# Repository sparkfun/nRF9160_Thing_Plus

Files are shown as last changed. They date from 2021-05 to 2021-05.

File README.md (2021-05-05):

SparkFun nRF9160 Thing Plus
========================================

SparkFun nRF9160 Thing Plus

[*SparkFun nRF9160 Thing Plus (17354)*](https://www.sparkfun.com/products/17354)

SparkFun has paired up with CircuitDojo to bring you the SparkFun nRF9160 Thing Plus, which features the powerful Nordic nRF9160 microcontroller in a feather-compatible footprint. This little chip is capable of both CAT M1 LTE and NB-IoT cellular communication and is designed to work with Zephyr, the go-to RTOS for embedded development.

Not only can you take advantage of Nordic’s advanced power states, but you can also put the device into a low power standby state. Laboratory measurements are putting that mode at about 2µA of current. 2µA! It also features a 3.3V Buck-Boost which helps get every mWh from your batteries as possible.

No batteries? No problem! You can plug or power your nRF9160 Thing Plus externally for AC/DC powered operation. Keep it on at all times for high availability scenarios. Power it the 5V pin or insert a micro-USB cable to keep things going.

Want to persist data? The nRF9160 Thing Plus has a 4MB external flash for storing data while offline. Using external flash with a filesystem like LitteFS and you’ll have a project to recon with!

Repository Contents
-------------------

* **/Hardware** - Eagle design files (.brd, .sch)
* **/Production** - Production panel files (.brd)

Documentation
--------------
* **[Hookup Guide](https://learn.sparkfun.com/tutorials/nrf9160-thing-plus-hookup-guide)** - Basic hookup guide for the SparkFun nRF9160 Thing Plus.

License Information
-------------------

This product is _**open source**_! 

Please review the LICENSE.md file for license information. 

If you have any questions or concerns on licensing, please contact technical support on our [SparkFun forums](https://forum.sparkfun.com/viewforum.php?f=152).

Distributed as-is; no warranty is given.

- Your friends at SparkFun.

_Designed in collaboration with [Jared Wolff](https://www.jaredwolff.com/) over at Circuit Dojo._

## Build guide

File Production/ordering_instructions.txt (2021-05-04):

panel size, 107x130mm
PCB thickness, 1.6mm
number of layers, 4
soldermask color, Red
silkscreen color, White
oz copper, 1oz
finish, HASL lead free
stencils, top+bottom
pcs per panel, 8
min trace width, 0.1500mm / 0.0059in
min drill size, 0.2540mm / 0.0100in
filename to layer stackup 1/2/3/4: GTL, GL2, GL3, GBL

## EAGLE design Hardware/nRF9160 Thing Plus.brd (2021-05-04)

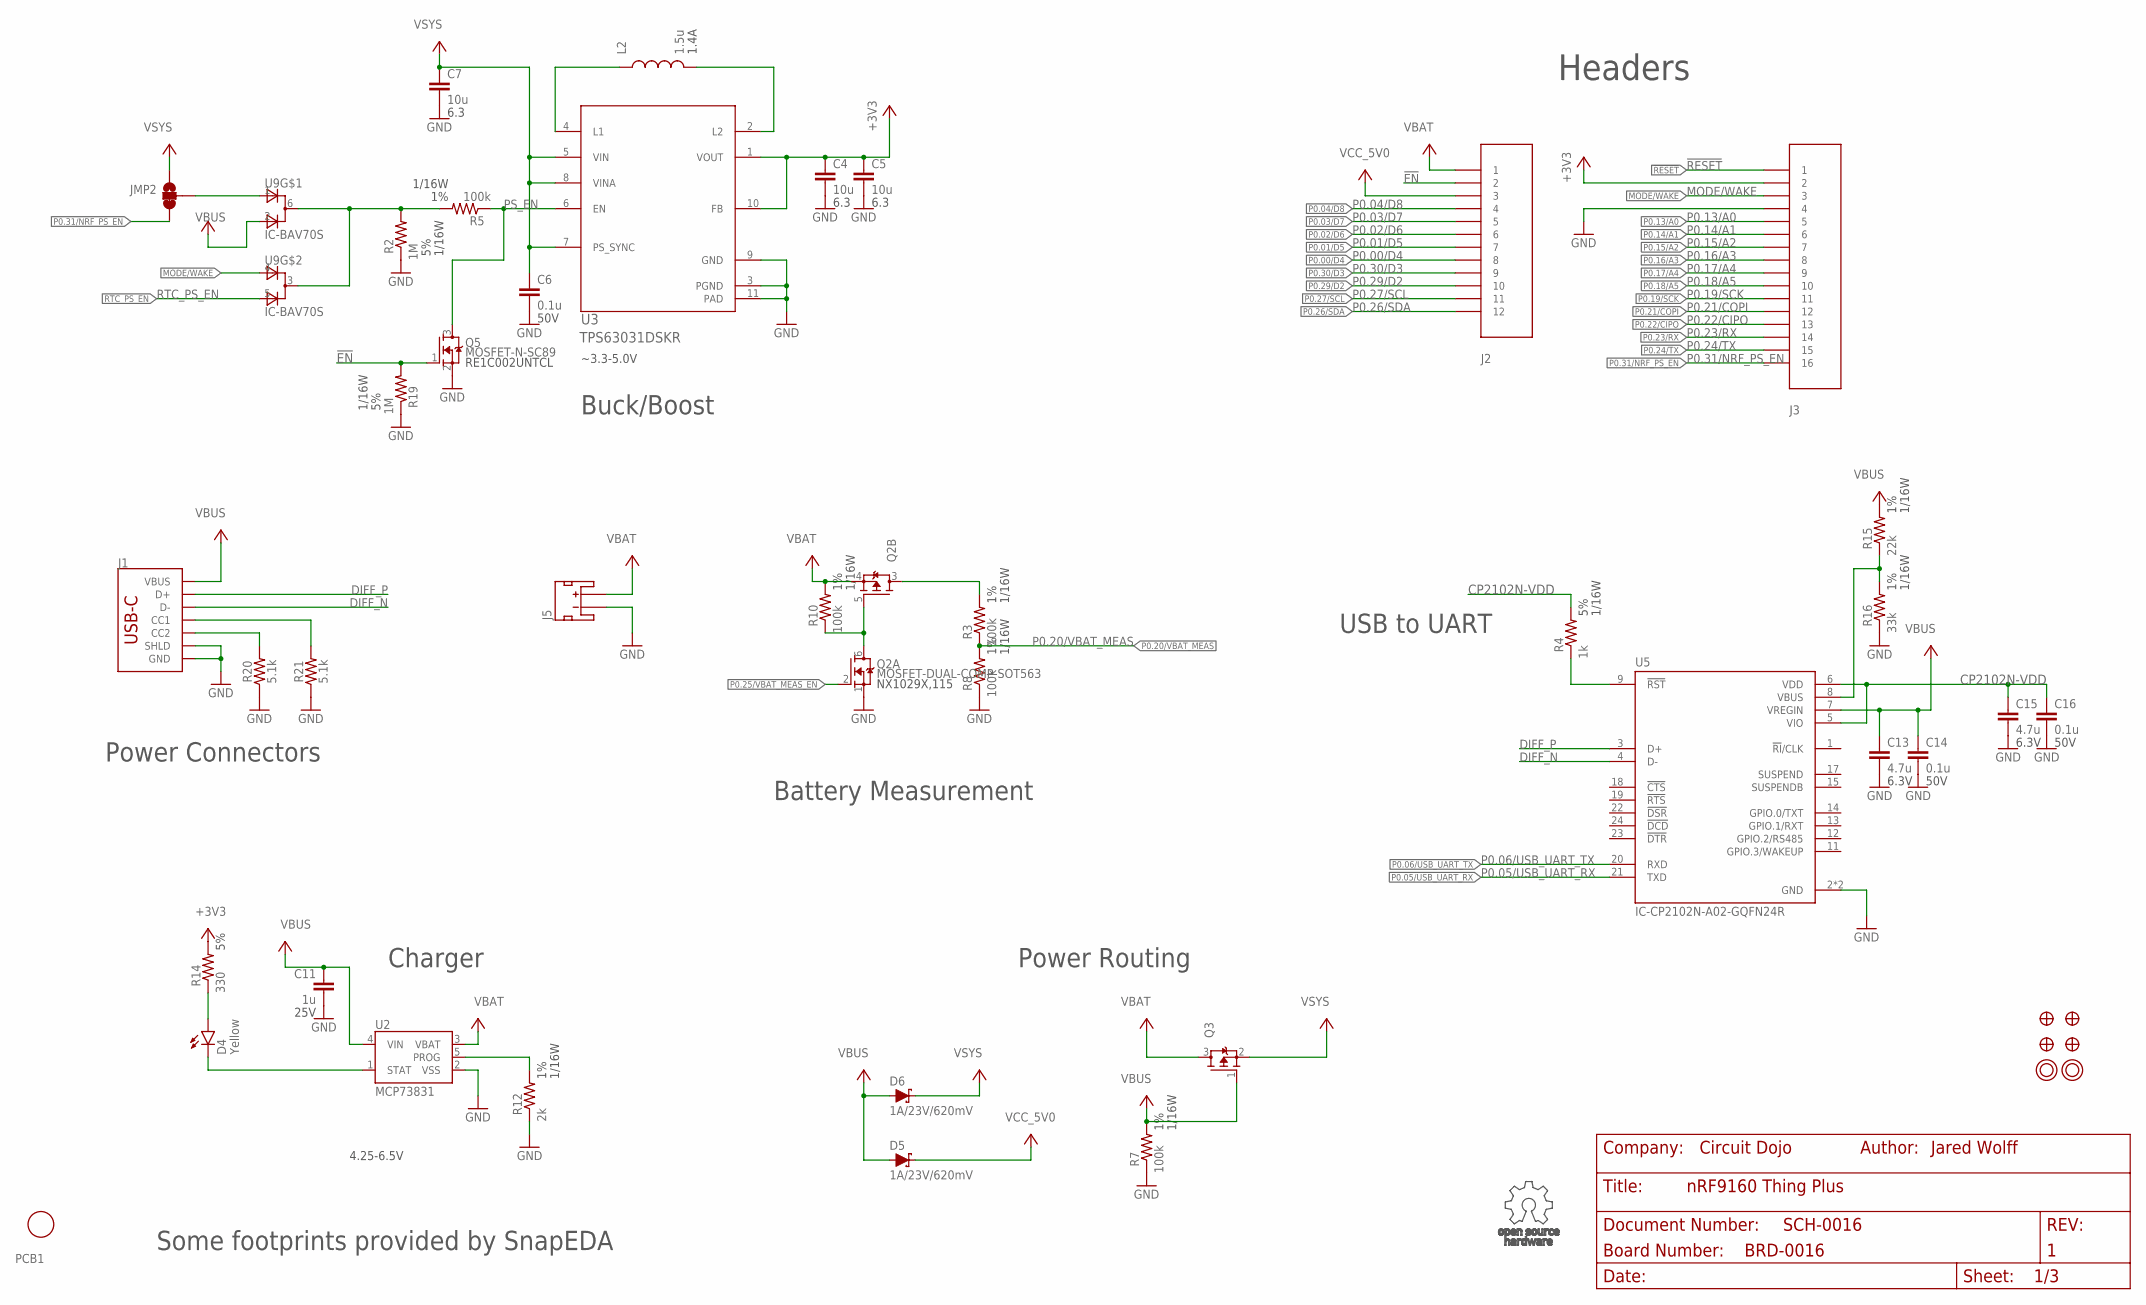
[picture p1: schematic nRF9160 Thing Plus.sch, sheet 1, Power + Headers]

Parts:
C4, C5, C7: 10u; C0603
C6, C14, C16: 0.1u; CAPC1005X55N
C11: 1u; CAPC1005X55N
C13, C15: 4.7u; C0603
D4: Yellow; LED-0603
D5, D6: 1A/23V/620mV; SOD-323
J1: USB Female C; USB-C-16P_4LAYER-PADS
J2: CON-HEADER-1X12-MALE-PIN
J3: CON-HEADER-1X16-MALE-PIN
J5: JST_2MM_MALE; JST-2-SMD
JMP2: JUMPER-3/1; JUMPER-ROUND-3-NO-R
L2: 1.5u; IND-2P0X2P0X1P2
PCB1: PCB-NRF91-FEATHER; PLACEHOLDER
Q2: MOSFET-DUAL-COMP-SOT563; SOT50P160X60-6N
Q3: MOSFET-P-20V-4.7A-SOT23; SOT23
Q5: MOSFET-N-SC89; DIO_RB558WMF-L
R2, R19: 1M; R0402-M
R3, R5, R7, R8, R10: 100k; R0402-M
R4: 1k; R0402-M
R12: 2k; R0402-M
R14: 330; R0402-M
R15: 22k; R0402-M
R16: 33k; R0402-M
R20, R21: 5.1k; 0402-TIGHT
U2: MCP73831; SOT23-5
U3: IC-TPS63031DSKR; DSK0010A
U5: IC-CP2102N-A02-GQFN24R; QFN50P400X400X80-25N
U9: IC-BAV70S; SOT363
U$3, U$4, U$24, U$35: FIDUCIAL-1MM
U$31, U$32: MOUNTING-HOLE-2.5MM-PLATED

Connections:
!EN: J2.2, Q5.1 (G), R19.2
!RESET: J3.1; also elsewhere on the board
+3V3: C4.1, C5.1, J3.2, R14.2, U3.1 (VOUT), U3.10 (FB); also elsewhere on the board
CHRG: D4.C, U2.1 (STAT)
CP212_VBUS: R15.1, R16.2, U5.8 (VBUS)
CP2102N-!RST: R4.1, U5.9 (!RST)
CP2102N-VDD: C15.1, C16.1, R4.2, U5.5 (VIO), U5.6 (VDD)
DIFF_N: J1.A7 (D-), J1.B7 (D-), U5.4 (D-)
DIFF_P: J1.A6 (D+), J1.B6 (D+), U5.3 (D+)
GND: C4.2, C5.2, C6.2, C7.2, C11.2, C13.2, C14.2, C15.2, C16.2, J1.GND, J1.GND2 (GND), J1.SHLD1 (SHLD), J1.SHLD2 (SHLD), J1.SHLD3 (SHLD), J1.SHLD4 (SHLD), J3.4, J5.1 (-), Q2.1 (S), Q5.2 (S), R2.1, R7.1, R8.1, R12.1, R16.1, R19.1, R20.1, R21.1, U2.2 (VSS), U3.3 (PGND), U3.9 (GND), U3.11 (PAD), U5.2 (GND), U5.25 (GND); also elsewhere on the board
MODE/WAKE: J3.3, U9.4 (A1); also elsewhere on the board
unnamed: L2.P$1 (1), U3.4 (L1)
unnamed: L2.P$2 (2), U3.2 (L2)
unnamed: J1.A5 (CC1), R21.2
unnamed: Q2.3 (D), R3.2
unnamed: Q2.5 (G), Q2.6 (D), R10.1
unnamed: J1.B5 (CC2), R20.2
unnamed: D4.A, R14.1
NRF_PS_EN_JMP: JMP2.P$2 (2), U9.1 (A1)
P0.00/D4: J2.8; also elsewhere on the board
P0.01/D5: J2.7; also elsewhere on the board
P0.02/D6: J2.6; also elsewhere on the board
P0.03/D7: J2.5; also elsewhere on the board
P0.04/D8: J2.4; also elsewhere on the board
P0.05/USB_UART_RX: U5.21 (TXD); also elsewhere on the board
P0.06/USB_UART_TX: U5.20 (RXD); also elsewhere on the board
P0.13/A0: J3.5; also elsewhere on the board
P0.14/A1: J3.6; also elsewhere on the board
P0.15/A2: J3.7; also elsewhere on the board
P0.16/A3: J3.8; also elsewhere on the board
P0.17/A4: J3.9; also elsewhere on the board
P0.18/A5: J3.10; also elsewhere on the board
P0.19/SCK: J3.11; also elsewhere on the board
P0.20/VBAT_MEAS: R3.1, R8.2; also elsewhere on the board
P0.21/COPI: J3.12; also elsewhere on the board
P0.22/CIPO: J3.13; also elsewhere on the board
P0.23/RX: J3.14; also elsewhere on the board
P0.24/TX: J3.15; also elsewhere on the board
P0.25/VBAT_MEAS_EN: Q2.2 (G); also elsewhere on the board
P0.26/SDA: J2.12; also elsewhere on the board
P0.27/SCL: J2.11; also elsewhere on the board
P0.29/D2: J2.10; also elsewhere on the board
P0.30/D3: J2.9; also elsewhere on the board
P0.31/NRF_PS_EN: J3.16, JMP2.P$3 (3); also elsewhere on the board
PROG: R12.2, U2.5 (PROG)
PS_EN: Q5.3 (D), R5.1, U3.6 (EN)
PS_EN_CC: R2.2, R5.2, U9.3 (C), U9.6 (C)
RTC_PS_EN: U9.5 (A2); also elsewhere on the board
VBAT: J2.1, J5.2 (+), Q2.4 (S), Q3.3 (D), R10.2, U2.3 (VBAT)
VBUS: C11.1, C13.1, C14.1, D5.A, D6.A, J1.VBUS1 (VBUS), J1.VBUS2 (VBUS), Q3.1 (G), R7.2, R15.2, U2.4 (VIN), U5.7 (VREGIN), U9.2 (A2)
VCC_5V0: D5.C, J2.3
VSYS: C6.1, C7.1, D6.C, JMP2.P$1 (1), Q3.2 (S), U3.5 (VIN), U3.7 (PS_SYNC), U3.8 (VINA); also elsewhere on the board

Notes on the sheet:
Headers
Some footprints provided by SnapEDA
Buck/Boost
Power Routing
Battery Measurement
Charger
USB to UART
Power Connectors
4.25-6.5V
~3.3-5.0V

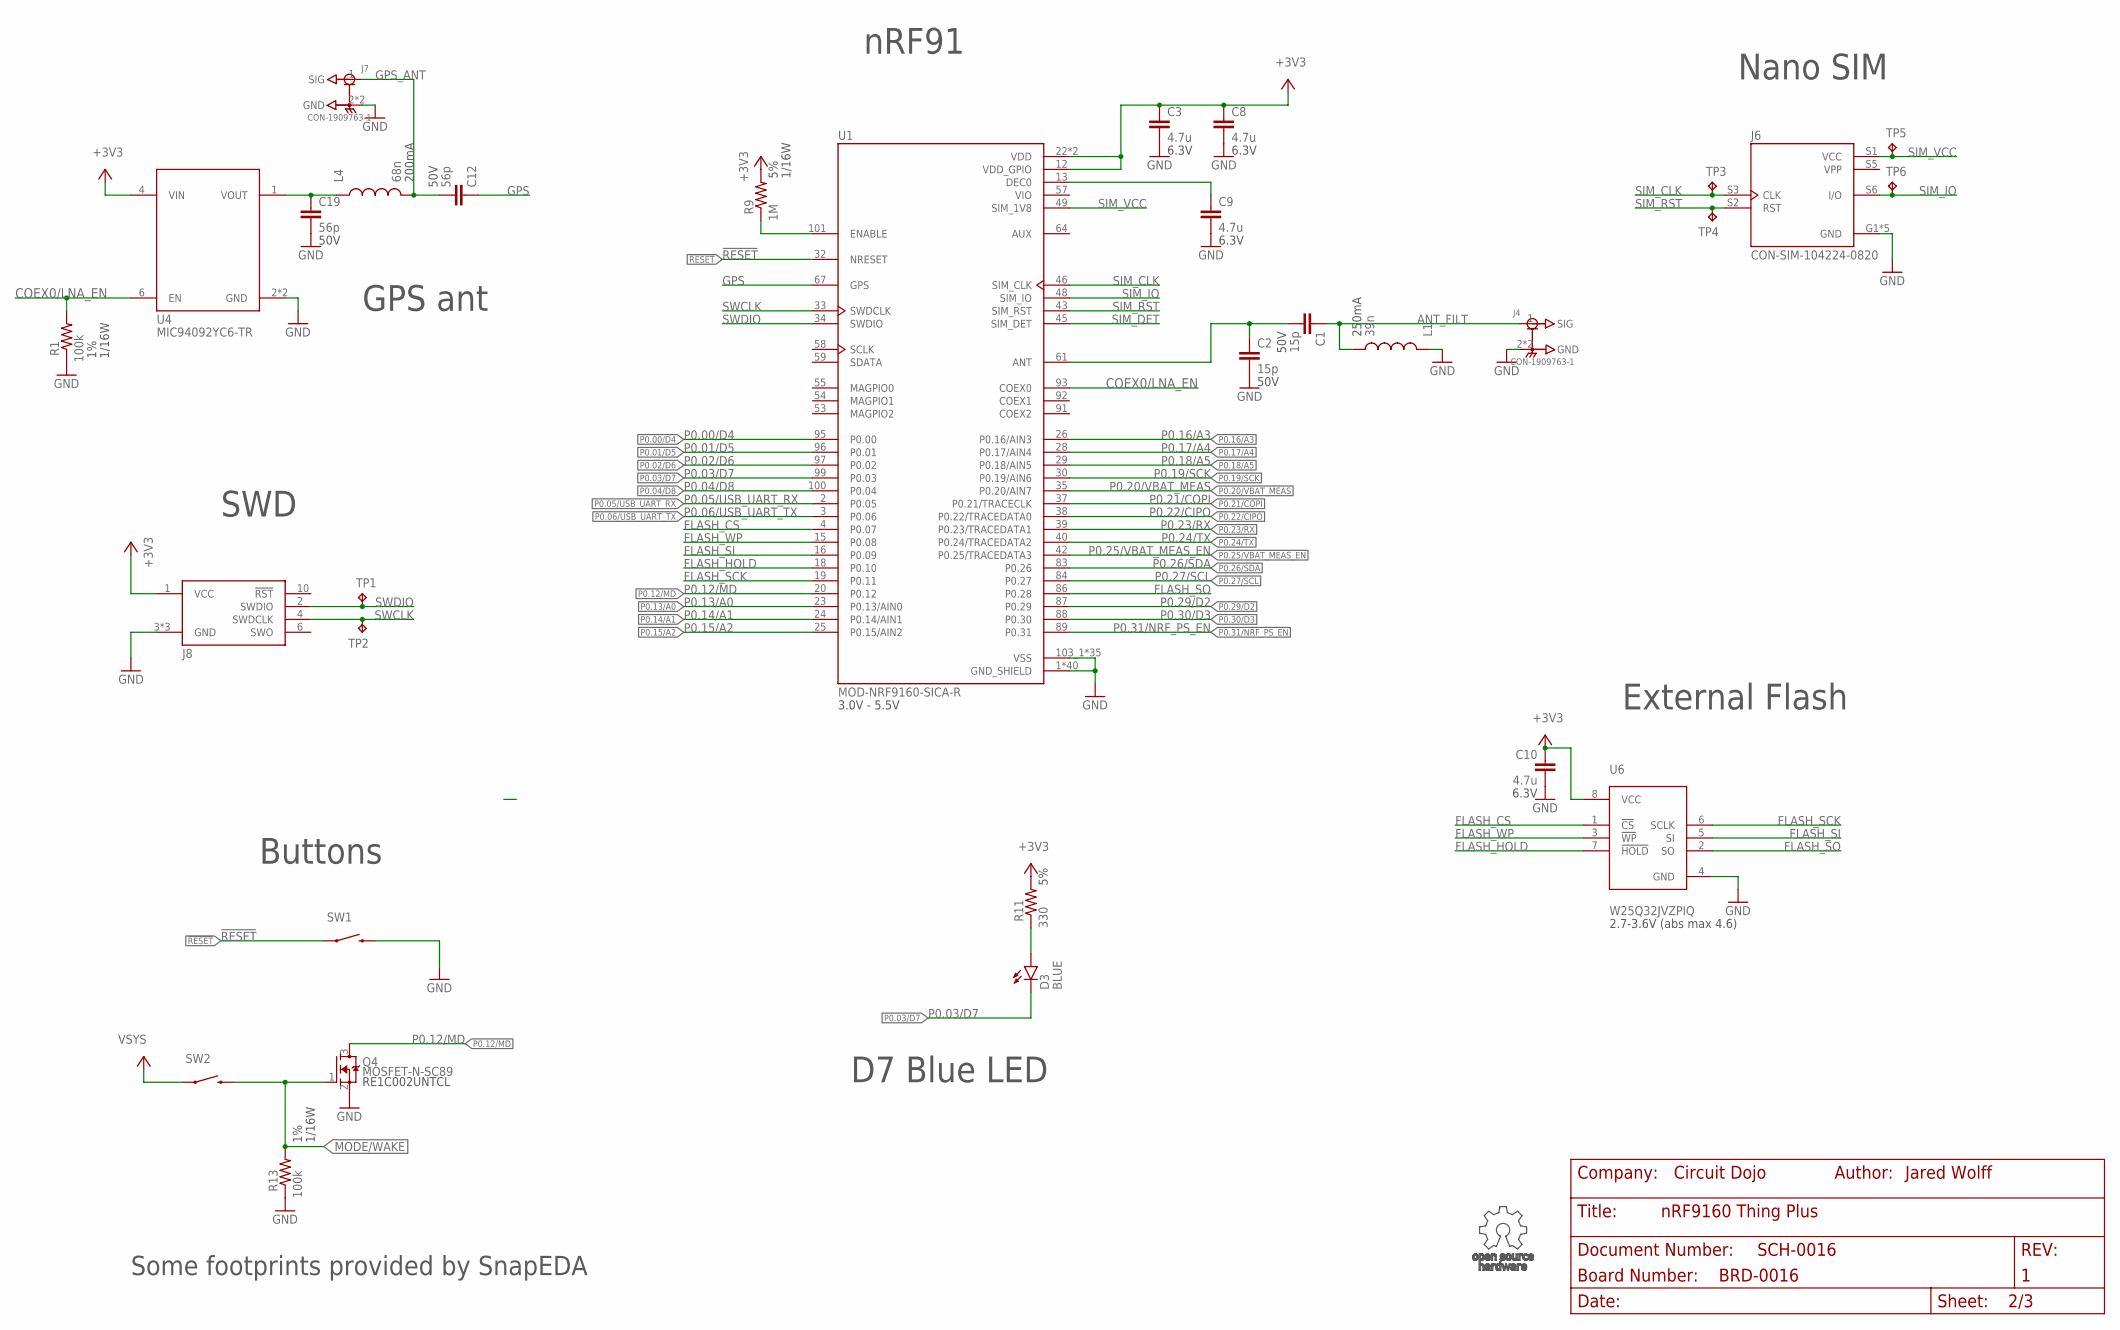
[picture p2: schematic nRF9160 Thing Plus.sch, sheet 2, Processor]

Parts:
C1, C2: 15p; CAPC1005X55N
C3, C8, C9, C10: 4.7u; C0603
C12, C19: 56p; CAPC1005X55N
D3: BLUE; LED-0603
J4, J7: CON-1909763-1; TE_1909763-1
J6: CON-SIM-104224-0820; MOLEX_104224-0820
J8: CON-FTSH-105-XX-X-DV; SAMTEC_FTSH-105-XX-X-DV
L1: 39n; IND0402_22N_TAI
L4: 68n; IND0402_22N_TAI
Q4: MOSFET-N-SC89; DIO_RB558WMF-L
R1, R13: 100k; R0402-M
R9: 1M; R0402-M
R11: 330; R0402-M
SW1, SW2: MOMENTARY-SWITCH-SPST-SMD-4.6X2.8MM; TACTILE_SWITCH_SMD_4.6X2.8MM
TP1, TP2, TP3, TP4, TP5, TP6: TP-1SIDE-1P0; TP-1P0
U1: MOD-NRF9160-SICA-R; NORDIC_NRF9160-SICA-R
U4: POWER-SWITCH-MIC94092YC6; SOT363
U6: FLASH-WSON; WIN_ZP-8-L

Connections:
!RESET: SW1.1, SW1.2 (1), U1.32 (NRESET); also elsewhere on the board
+3V3: C3.1, C8.1, C10.1, J8.1 (VCC), R9.2, R11.2, U1.12 (VDD_GPIO), U1.22 (VDD), U1.102 (VDD), U4.4 (VIN), U6.8 (VCC); also elsewhere on the board
ANT: C1.2, C2.1, U1.61 (ANT)
ANT_FILT: C1.1, J4.1 (SIG), L1.2
COEX0/LNA_EN: R1.2, U1.93 (COEX0), U4.6 (EN)
FLASH_CS: U1.4 (P0.07), U6.1 (!CS)
FLASH_HOLD: U1.18 (P0.10), U6.7 (!HOLD)
FLASH_SCK: U1.19 (P0.11), U6.6 (SCLK)
FLASH_SI: U1.16 (P0.09), U6.5 (SI)
FLASH_SO: U1.86 (P0.28), U6.2 (SO)
FLASH_WP: U1.15 (P0.08), U6.3 (!WP)
GND: C2.2, C3.2, C8.2, C9.2, C10.2, C19.2, J4.2 (GND), J4.3 (GND), J6.G1 (GND), J6.G2 (GND), J6.G3 (GND), J6.G4 (GND), J6.S4 (GND), J7.2 (GND), J7.3 (GND), J8.3 (GND), J8.5 (GND), J8.9 (GND), L1.1, Q4.2 (S), R1.1, R13.1, SW1.3 (2), SW1.4 (2), U1.1 (GND_SHIELD), U1.5 (GND_SHIELD), U1.6 (GND_SHIELD), U1.7 (GND_SHIELD), U1.8 (GND_SHIELD), U1.9 (GND_SHIELD), U1.11 (GND_SHIELD), U1.14 (GND_SHIELD), U1.17 (GND_SHIELD), U1.21 (GND_SHIELD), U1.27 (GND_SHIELD), U1.31 (GND_SHIELD), U1.36 (GND_SHIELD), U1.41 (GND_SHIELD), U1.44 (GND_SHIELD), U1.47 (GND_SHIELD), U1.50 (GND_SHIELD), U1.52 (GND_SHIELD), U1.56 (GND_SHIELD), U1.60 (GND_SHIELD), U1.62 (GND_SHIELD), U1.63 (GND_SHIELD), U1.65 (GND_SHIELD), U1.66 (GND_SHIELD), U1.68 (GND_SHIELD), U1.69 (GND_SHIELD), U1.72 (GND_SHIELD), U1.74 (GND_SHIELD), U1.75 (GND_SHIELD), U1.76 (GND_SHIELD), U1.77 (GND_SHIELD), U1.78 (GND_SHIELD), U1.79 (GND_SHIELD), U1.80 (GND_SHIELD), U1.81 (GND_SHIELD), U1.82 (GND_SHIELD), U1.85 (GND_SHIELD), U1.90 (GND_SHIELD), U1.94 (GND_SHIELD), U1.98 (GND_SHIELD), U1.103_1 (VSS), U1.103_2 (VSS), U1.103_3 (VSS), U1.103_4 (VSS), U1.103_5 (VSS), U1.103_6 (VSS), U1.103_7 (VSS), U1.103_8 (VSS), U1.103_9 (VSS), U1.103_10 (VSS), U1.103_11 (VSS), U1.103_12 (VSS), U1.103_13 (VSS), U1.103_14 (VSS), U1.103_15 (VSS), U1.103_16 (VSS), U1.103_17 (VSS), U1.103_18 (VSS), U1.103_19 (VSS), U1.103_20 (VSS), U1.103_21 (VSS), U1.103_22 (VSS), U1.103_23 (VSS), U1.103_24 (VSS), U1.103_25 (VSS), U1.103_26 (VSS), U1.103_27 (VSS), U1.103_28 (VSS), U1.103_29 (VSS), U1.103_30 (VSS), U1.103_31 (VSS), U1.103_32 (VSS), U1.103_33 (VSS), U1.103_34 (VSS), U1.103_35 (VSS), U4.2 (GND), U4.5 (GND), U6.4 (GND); also elsewhere on the board
GPS: C12.1, U1.67 (GPS)
GPS_ANT: C12.2, J7.1 (SIG), L4.2
LNA_SW_OUT: C19.1, L4.1, U4.1 (VOUT)
MODE/WAKE: Q4.1 (G), R13.2, SW2.3 (2), SW2.4 (2); also elsewhere on the board
unnamed: R9.1, U1.101 (ENABLE)
unnamed: C9.1, U1.13 (DEC0)
unnamed: D3.A, R11.1
P0.00/D4: U1.95 (P0.00); also elsewhere on the board
P0.01/D5: U1.96 (P0.01); also elsewhere on the board
P0.02/D6: U1.97 (P0.02); also elsewhere on the board
P0.03/D7: D3.C, U1.99 (P0.03); also elsewhere on the board
P0.04/D8: U1.100 (P0.04); also elsewhere on the board
P0.05/USB_UART_RX: U1.2 (P0.05); also elsewhere on the board
P0.06/USB_UART_TX: U1.3 (P0.06); also elsewhere on the board
P0.12/MD: Q4.3 (D), U1.20 (P0.12)
P0.13/A0: U1.23 (P0.13/AIN0); also elsewhere on the board
P0.14/A1: U1.24 (P0.14/AIN1); also elsewhere on the board
P0.15/A2: U1.25 (P0.15/AIN2); also elsewhere on the board
P0.16/A3: U1.26 (P0.16/AIN3); also elsewhere on the board
P0.17/A4: U1.28 (P0.17/AIN4); also elsewhere on the board
P0.18/A5: U1.29 (P0.18/AIN5); also elsewhere on the board
P0.19/SCK: U1.30 (P0.19/AIN6); also elsewhere on the board
P0.20/VBAT_MEAS: U1.35 (P0.20/AIN7); also elsewhere on the board
P0.21/COPI: U1.37 (P0.21/TRACECLK); also elsewhere on the board
P0.22/CIPO: U1.38 (P0.22/TRACEDATA0); also elsewhere on the board
P0.23/RX: U1.39 (P0.23/TRACEDATA1); also elsewhere on the board
P0.24/TX: U1.40 (P0.24/TRACEDATA2); also elsewhere on the board
P0.25/VBAT_MEAS_EN: U1.42 (P0.25/TRACEDATA3); also elsewhere on the board
P0.26/SDA: U1.83 (P0.26); also elsewhere on the board
P0.27/SCL: U1.84 (P0.27); also elsewhere on the board
P0.29/D2: U1.87 (P0.29); also elsewhere on the board
P0.30/D3: U1.88 (P0.30); also elsewhere on the board
P0.31/NRF_PS_EN: U1.89 (P0.31); also elsewhere on the board
SIM_CLK: J6.S3 (CLK), TP3.TP, U1.46 (SIM_CLK)
SIM_DET: U1.45 (SIM_DET)
SIM_IO: J6.S6 (I/O), TP6.TP, U1.48 (SIM_IO)
SIM_RST: J6.S2 (RST), TP4.TP, U1.43 (SIM_RST)
SIM_VCC: J6.S1 (VCC), TP5.TP, U1.49 (SIM_1V8)
SWCLK: J8.4 (SWDCLK), TP2.TP, U1.33 (SWDCLK)
SWDIO: J8.2 (SWDIO), TP1.TP, U1.34 (SWDIO)
VIO: U1.57 (VIO)
VPP: J6.S5 (VPP)
VSYS: SW2.1, SW2.2 (1); also elsewhere on the board

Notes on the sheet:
Some footprints provided by SnapEDA
nRF91
SWD
Buttons
External Flash
D7 Blue LED
3.0V - 5.5V
2.7-3.6V (abs max 4.6)
GPS ant
Nano SIM

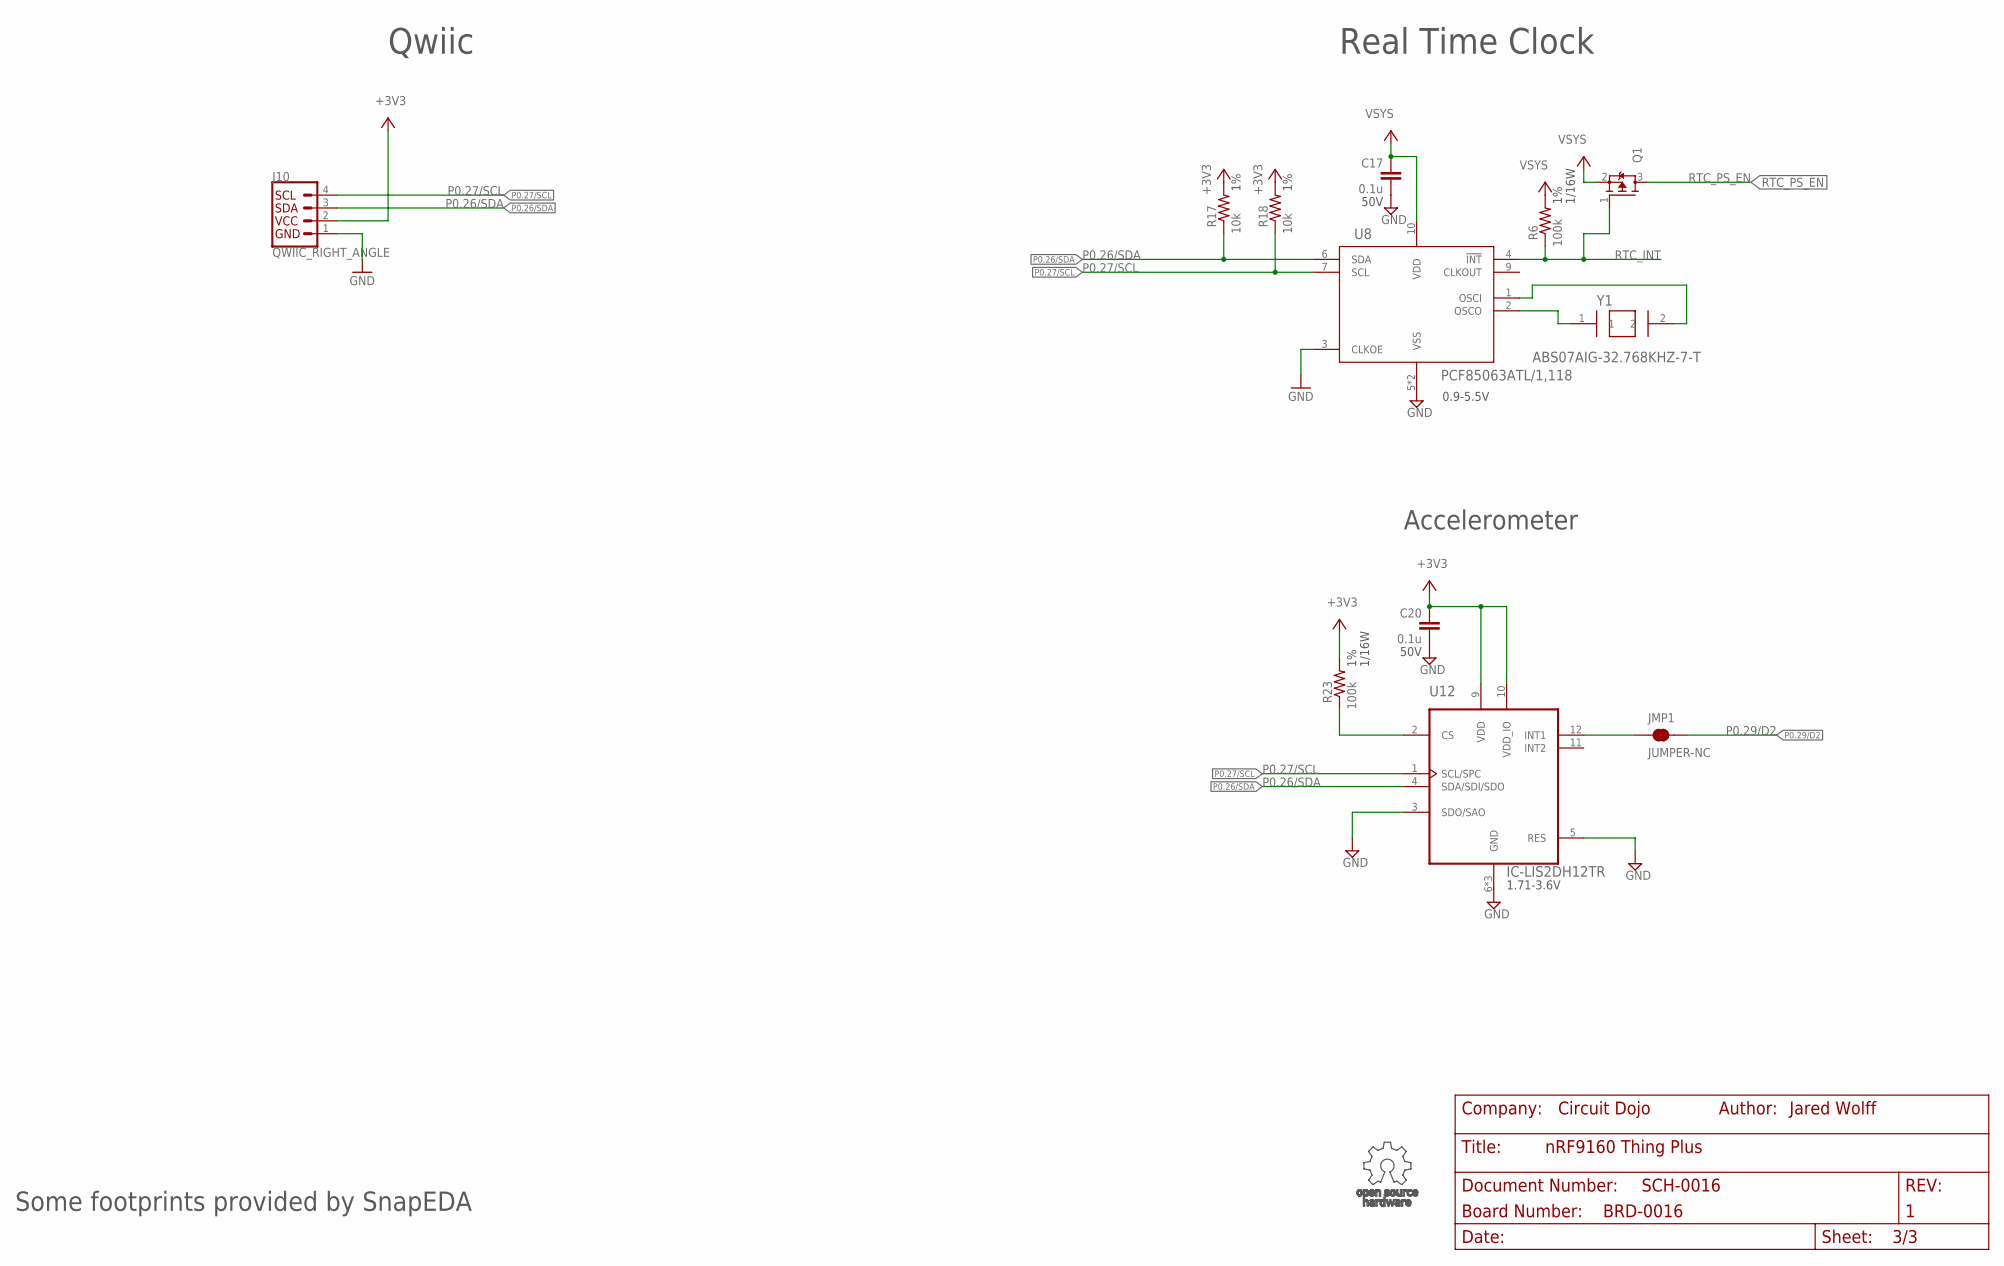
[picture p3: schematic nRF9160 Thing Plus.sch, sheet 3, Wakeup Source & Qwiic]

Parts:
C17, C20: 0.1u; CAPC1005X55N
J10: QWIIC_RIGHT_ANGLE; JST04_1MM_RA
JMP1: JUMPER-NC; JUMPER-ROUND-NC
Q1: MOSFET-P-SC89; DIO_RB558WMF-L
R6, R23: 100k; R0402-M
R17, R18: 10k; R0402-M
U8: IC-PCF85063ATL/1; DFN10_2P7X2P7-L
U12: IC-LIS2DH12TR; PQFN50P200X200100-12N
Y1: XTAL-ABS07AIG-32.768KHZ-7-T; XTAL320X150X90

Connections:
+3V3: C20.1, J10.2, R17.2, R18.2, R23.2, U12.9 (VDD), U12.10 (VDD_IO); also elsewhere on the board
GND: C17.2, C20.2, J10.1, U8.3 (CLKOE), U8.5 (VSS), U8.11 (VSS), U12.3 (SDO/SAO), U12.5 (RES), U12.6 (GND), U12.7 (GND), U12.8 (GND); also elsewhere on the board
unnamed: U8.1 (OSCI), Y1.2
unnamed: R23.1, U12.2 (CS)
unnamed: JMP1.P$1 (1), U12.12 (INT1)
unnamed: U8.2 (OSCO), Y1.1
P0.26/SDA: J10.3, R17.1, U8.6 (SDA), U12.4 (SDA/SDI/SDO); also elsewhere on the board
P0.27/SCL: J10.4, R18.1, U8.7 (SCL), U12.1 (SCL/SPC); also elsewhere on the board
P0.29/D2: JMP1.P$2 (2); also elsewhere on the board
RTC_INT: Q1.1 (G), R6.1, U8.4 (!INT)
RTC_PS_EN: Q1.3 (D); also elsewhere on the board
VSYS: C17.1, Q1.2 (S), R6.2, U8.10 (VDD); also elsewhere on the board

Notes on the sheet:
Some footprints provided by SnapEDA
Real Time Clock
0.9-5.5V
Qwiic
Accelerometer
1.71-3.6V

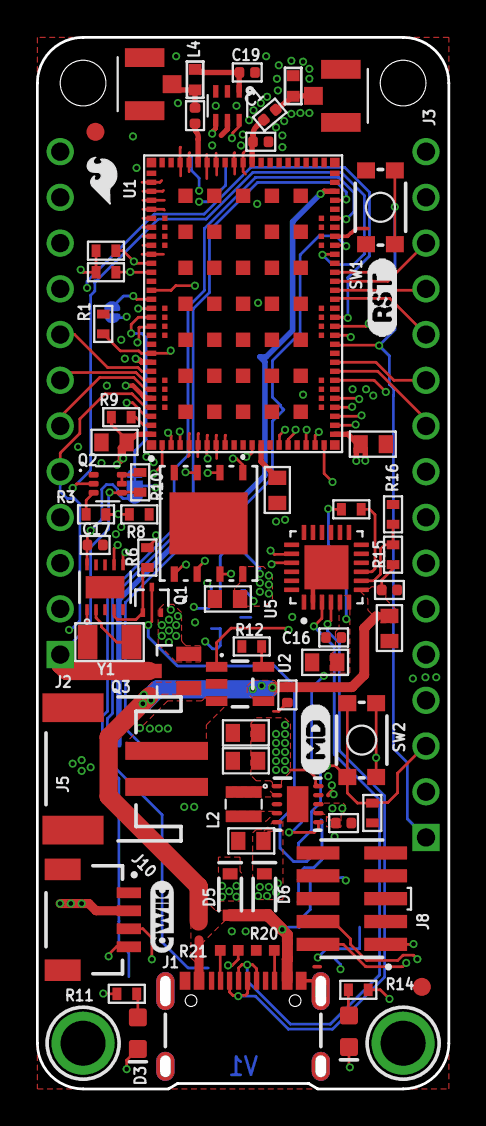
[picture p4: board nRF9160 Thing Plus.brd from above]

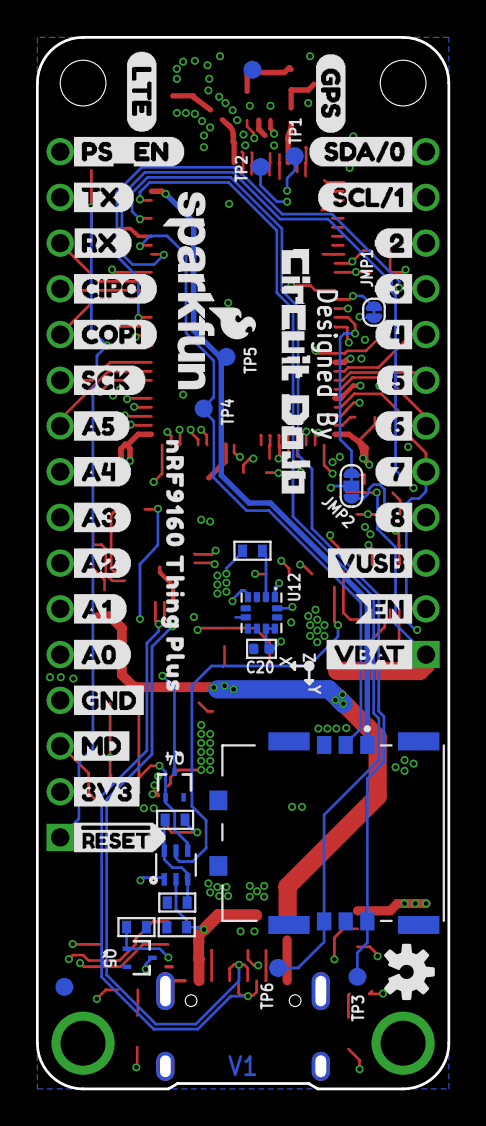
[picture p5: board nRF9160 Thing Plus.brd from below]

Board: 4 copper layers, 22.9 x 58.4 mm, 128 parts (55 on the bottom side), 79 nets.

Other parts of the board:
LOGO5: OSHW-LOGOS; OSHW-LOGO-S
U$1: SFE_LOGO_NAME_FLAME_.1
U$2: LOGO-CIRCUITDOJO
U$5: A3L-LOC
U$6: QWIIC_4MM
U$7: RST0
U$8: PS_EN0
U$9, U$14: MD0
U$10: 20
U$11: 30
U$12: SCL#11
U$13: SDA#00
U$15: SFE_LOGO_FLAME_.1
U$16: TX0
U$17: RX0
U$18: SCK0
U$19: CIPO0
U$20: COPI0
U$21: GPS0
U$22: LTE0
U$23: NRF9160_THING_PLUS0
U$69: GND12
U$71: 3V314
U$72: #RESET15
U$73: VUSB25
U$74: EN26
U$75: VBAT27
U$83: A56
U$84: A47
U$85: A38
U$86: A29
U$87: A110
U$88: A011
U$89: 412
U$90: 513
U$91: 614
U$92: 715
U$93: 816

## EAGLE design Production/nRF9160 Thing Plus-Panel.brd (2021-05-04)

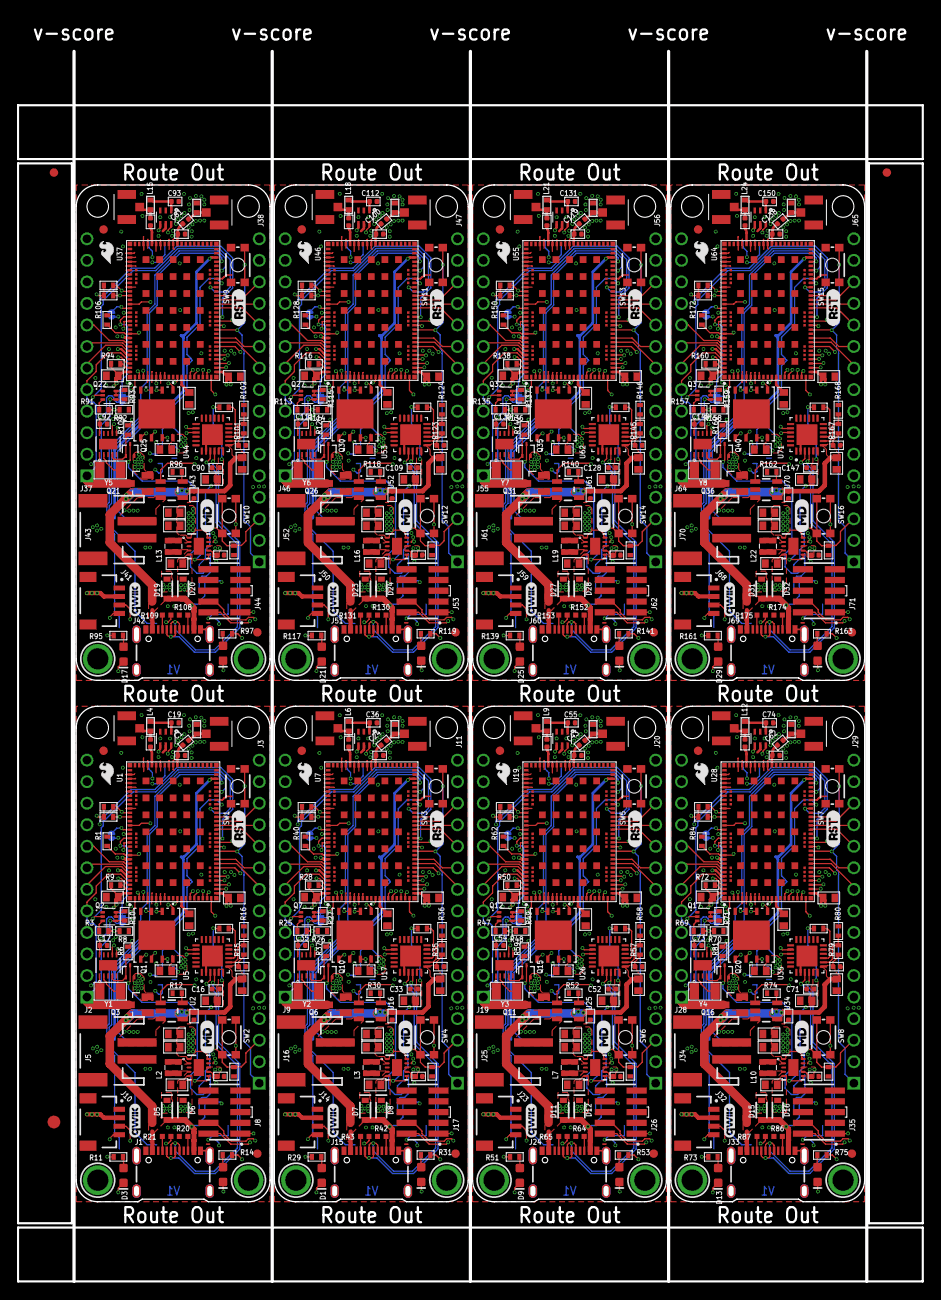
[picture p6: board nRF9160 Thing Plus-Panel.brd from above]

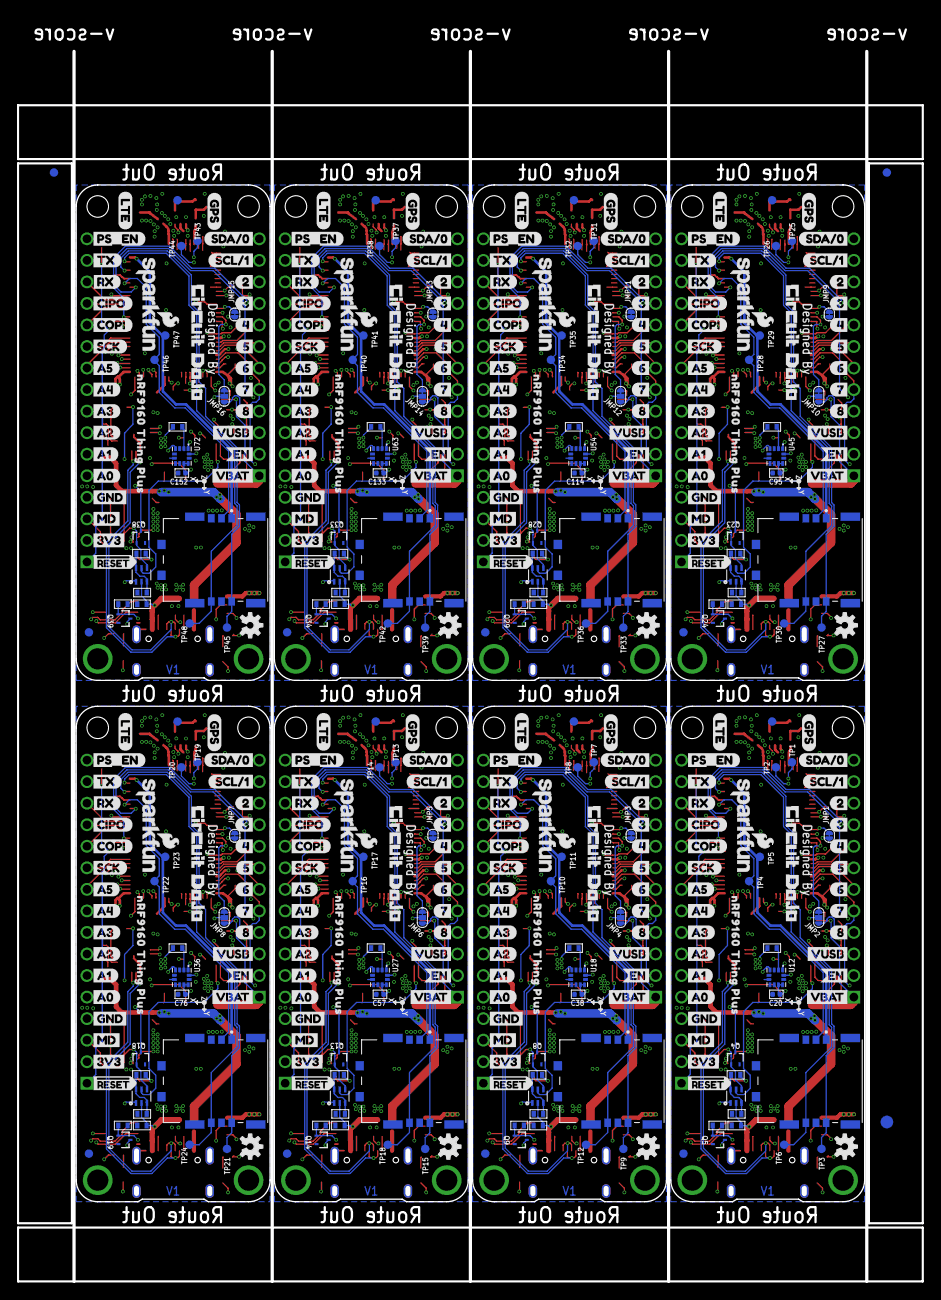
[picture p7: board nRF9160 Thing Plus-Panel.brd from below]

Board: 4 copper layers, 106.7 x 145.0 mm, 1030 parts (443 on the bottom side), 632 nets.

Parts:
C1, C2, C24, C37, C43, C56, C62, C75, C81, C94, C100, C113, C119, C132, C138, C151: 15p; CAPC1005X55N
C3, C8, C9, C10, C13, C15, C25, C26, C27, C28, C30, C32, C44, C45, C46, C47, C49, C51, C63, C64, C65, C66, C68, C70, C82, C83, C84, C85, C87, C89, C101, C102, C103, C104, C106, C108, C120, C121, C122, C123, C125, C127, C139, C140, C141, C142, C144, C146: 4.7u; C0603
C4, C5, C7, C18, C21, C22, C39, C40, C41, C58, C59, C60, C77, C78, C79, C96, C97, C98, C115, C116, C117, C134, C135, C136: 10u; C0603
C6, C14, C16, C17, C20, C23, C31, C33, C35, C38, C42, C50, C52, C54, C57, C61, C69, C71, C73, C76, C80, C88, C90, C92, C95, C99, C107, C109, C111, C114, C118, C126, C128, C130, C133, C137, C145, C147, C149, C152: 0.1u; CAPC1005X55N
C11, C29, C48, C67, C86, C105, C124, C143: 1u; CAPC1005X55N
C12, C19, C34, C36, C53, C55, C72, C74, C91, C93, C110, C112, C129, C131, C148, C150: 56p; CAPC1005X55N
D1, D3, D9, D13, D17, D21, D25, D29: BLUE; LED-0603
D2, D4, D10, D14, D18, D22, D26, D30: Yellow; LED-0603
D5, D6, D7, D8, D11, D12, D15, D16, D19, D20, D23, D24, D27, D28, D31, D32: 1A/23V/620mV; SOD-323
E$1, E$2, E$3, E$4: FIDUCIAL-1X2
E$5, E$6: FIDUCIAL-1.5X3
J1, J15, J24, J33, J42, J51, J60, J69: USB Female C; USB-C-16P_4LAYER-PADS
J2, J9, J19, J28, J37, J46, J55, J64: CON-HEADER-1X12-MALE-PIN
J3, J11, J20, J29, J38, J47, J56, J65: CON-HEADER-1X16-MALE-PIN
J4, J7, J12, J13, J21, J22, J30, J31, J39, J40, J48, J49, J57, J58, J66, J67: CON-1909763-1; TE_1909763-1
J5, J16, J25, J34, J43, J52, J61, J70: JST-2-SMD
J6, J18, J27, J36, J45, J54, J63, J72: CON-SIM-104224-0820; MOLEX_104224-0820
J8, J17, J26, J35, J44, J53, J62, J71: CON-FTSH-105-XX-X-DV; SAMTEC_FTSH-105-XX-X-DV
J10, J14, J23, J32, J41, J50, J59, J68: QWIIC_RIGHT_ANGLE; JST04_1MM_RA
JMP1, JMP3, JMP5, JMP7, JMP9, JMP11, JMP13, JMP15: JUMPER-NC; JUMPER-ROUND-NC
JMP2, JMP4, JMP6, JMP8, JMP10, JMP12, JMP14, JMP16: JUMPER-3/1; JUMPER-ROUND-3-NO-R
L1, L5, L8, L11, L14, L17, L20, L23: 39n; IND0402_22N_TAI
L2, L3, L7, L10, L13, L16, L19, L22: 1.5u; IND-2P0X2P0X1P2
L4, L6, L9, L12, L15, L18, L21, L24: 68n; IND0402_22N_TAI
LOGO1, LOGO2, LOGO3, LOGO4, LOGO5, LOGO6, LOGO7, LOGO8: OSHW-LOGOS; OSHW-LOGO-S
PCB1, PCB2, PCB3, PCB4, PCB5, PCB6, PCB7, PCB8: PCB-NRF91-FEATHER; PLACEHOLDER
Q1, Q10, Q15, Q20, Q25, Q30, Q35, Q40: MOSFET-P-SC89; DIO_RB558WMF-L
Q2, Q7, Q12, Q17, Q22, Q27, Q32, Q37: MOSFET-DUAL-COMP-SOT563; SOT50P160X60-6N
Q3, Q6, Q11, Q16, Q21, Q26, Q31, Q36: MOSFET-P-20V-4.7A-SOT23; SOT23
Q4, Q5, Q8, Q9, Q13, Q14, Q18, Q19, Q23, Q24, Q28, Q29, Q33, Q34, Q38, Q39: MOSFET-N-SC89; DIO_RB558WMF-L
R1, R3, R5, R6, R7, R8, R10, R13, R22, R23, R25, R26, R27, R32, R34, R37, R40, R44, R45, R47, R48, R49, R54, R56, R59, R62, R66, R67, R69, R70, R71, R76, R78, R81, R84, R88, R89, R91, R92, R93, R98, R100, R103, R106, R110, R111, R113, R114, R115, R120, R122, R125, R128, R132, R133, R135, R136, R137, R142, R144, R147, R150, R154, R155, R157, R158, R159, R164, R166, R169, R172, R176: 100k; R0402-M
R2, R9, R19, R24, R28, R41, R46, R50, R63, R68, R72, R85, R90, R94, R107, R112, R116, R129, R134, R138, R151, R156, R160, R173: 1M; R0402-M
R4, R33, R55, R77, R99, R121, R143, R165: 1k; R0402-M
R11, R14, R29, R31, R51, R53, R73, R75, R95, R97, R117, R119, R139, R141, R161, R163: 330; R0402-M
R12, R30, R52, R74, R96, R118, R140, R162: 2k; R0402-M
R15, R35, R57, R79, R101, R123, R145, R167: 22k; R0402-M
R16, R36, R58, R80, R102, R124, R146, R168: 33k; R0402-M
R17, R18, R38, R39, R60, R61, R82, R83, R104, R105, R126, R127, R148, R149, R170, R171: 10k; R0402-M
R20, R21, R42, R43, R64, R65, R86, R87, R108, R109, R130, R131, R152, R153, R174, R175: 5.1k; 0402-TIGHT
SW1, SW2, SW3, SW4, SW5, SW6, SW7, SW8, SW9, SW10, SW11, SW12, SW13, SW14, SW15, SW16: MOMENTARY-SWITCH-SPST-SMD-4.6X2.8MM; TACTILE_SWITCH_SMD_4.6X2.8MM
TP1, TP2, TP3, TP4, TP5, TP6, TP7, TP8, TP9, TP10, TP11, TP12, TP13, TP14, TP15, TP16, TP17, TP18, TP19, TP20, TP21, TP22, TP23, TP24, TP25, TP26, TP27, TP28, TP29, TP30, TP31, TP32, TP33, TP34, TP35, TP36, TP37, TP38, TP39, TP40, TP41, TP42, TP43, TP44, TP45, TP46, TP47, TP48: TP-1SIDE-1P0; TP-1P0
U1, U7, U19, U28, U37, U46, U55, U64: MOD-NRF9160-SICA-R; NORDIC_NRF9160-SICA-R
U2, U16, U25, U34, U43, U52, U61, U70: MCP73831; SOT23-5
U3, U11, U21, U30, U39, U48, U57, U66: IC-TPS63031DSKR; DSK0010A
U4, U15, U24, U33, U42, U51, U60, U69: POWER-SWITCH-MIC94092YC6; SOT363
U5, U17, U26, U35, U44, U53, U62, U71: IC-CP2102N-A02-GQFN24R; QFN50P400X400X80-25N
U6, U10, U20, U29, U38, U47, U56, U65: FLASH-WSON; WIN_ZP-8-L
U8, U13, U22, U31, U40, U49, U58, U67: IC-PCF85063ATL/1; DFN10_2P7X2P7-L
U9, U14, U23, U32, U41, U50, U59, U68: IC-BAV70S; SOT363
U12, U18, U27, U36, U45, U54, U63, U72: IC-LIS2DH12TR; PQFN50P200X200100-12N
U$1, U$66, U$127, U$171, U$215, U$259, U$303, U$347: SFE_LOGO_NAME_FLAME_.1
U$2, U$28, U$81, U$136, U$180, U$224, U$268, U$312: LOGO-CIRCUITDOJO
U$3, U$4, U$24, U$25, U$29, U$30, U$35, U$77, U$78, U$82, U$94, U$132, U$133, U$137, U$138, U$176, U$177, U$181, U$182, U$220, U$221, U$225, U$226, U$264, U$265, U$269, U$270, U$308, U$309, U$313, U$314, U$352: FIDUCIAL-1MM
U$5, U$33, U$95, U$139, U$183, U$227, U$271, U$315: A3L-LOC
U$6, U$34, U$96, U$140, U$184, U$228, U$272, U$316: QWIIC_4MM
U$7, U$61, U$122, U$166, U$210, U$254, U$298, U$342: RST0
U$8, U$67, U$128, U$172, U$216, U$260, U$304, U$348: PS_EN0
U$9, U$14, U$55, U$62, U$116, U$123, U$160, U$167, U$204, U$211, U$248, U$255, U$292, U$299, U$336, U$343: MD0
U$10, U$53, U$114, U$158, U$202, U$246, U$290, U$334: 20
U$11, U$54, U$115, U$159, U$203, U$247, U$291, U$335: 30
U$12, U$70, U$130, U$174, U$218, U$262, U$306, U$350: SCL#11
U$13, U$76, U$131, U$175, U$219, U$263, U$307, U$351: SDA#00
U$15, U$63, U$124, U$168, U$212, U$256, U$300, U$344: SFE_LOGO_FLAME_.1
U$16, U$56, U$117, U$161, U$205, U$249, U$293, U$337: TX0
U$17, U$57, U$118, U$162, U$206, U$250, U$294, U$338: RX0
U$18, U$58, U$119, U$163, U$207, U$251, U$295, U$339: SCK0
U$19, U$59, U$120, U$164, U$208, U$252, U$296, U$340: CIPO0
U$20, U$60, U$121, U$165, U$209, U$253, U$297, U$341: COPI0
U$21, U$64, U$125, U$169, U$213, U$257, U$301, U$345: GPS0
U$22, U$65, U$126, U$170, U$214, U$258, U$302, U$346: LTE0
U$23, U$68, U$129, U$173, U$217, U$261, U$305, U$349: NRF9160_THING_PLUS0
U$26, U$27, U$31, U$32, U$79, U$80, U$134, U$135, U$178, U$179, U$222, U$223, U$266, U$267, U$310, U$311: MOUNTING-HOLE-2.5MM-PLATED
U$36, U$69, U$97, U$141, U$185, U$229, U$273, U$317: GND12
U$37, U$71, U$98, U$142, U$186, U$230, U$274, U$318: 3V314
U$38, U$72, U$99, U$143, U$187, U$231, U$275, U$319: #RESET15
U$39, U$73, U$100, U$144, U$188, U$232, U$276, U$320: VUSB25
U$40, U$74, U$101, U$145, U$189, U$233, U$277, U$321: EN26
U$41, U$75, U$102, U$146, U$190, U$234, U$278, U$322: VBAT27
U$42, U$83, U$103, U$147, U$191, U$235, U$279, U$323: A56
U$43, U$84, U$104, U$148, U$192, U$236, U$280, U$324: A47
U$44, U$85, U$105, U$149, U$193, U$237, U$281, U$325: A38
U$45, U$86, U$106, U$150, U$194, U$238, U$282, U$326: A29
U$46, U$87, U$107, U$151, U$195, U$239, U$283, U$327: A110
U$47, U$88, U$108, U$152, U$196, U$240, U$284, U$328: A011
U$48, U$89, U$109, U$153, U$197, U$241, U$285, U$329: 412
U$49, U$90, U$110, U$154, U$198, U$242, U$286, U$330: 513
U$50, U$91, U$111, U$155, U$199, U$243, U$287, U$331: 614
U$51, U$92, U$112, U$156, U$200, U$244, U$288, U$332: 715
U$52, U$93, U$113, U$157, U$201, U$245, U$289, U$333: 816
Y1, Y2, Y3, Y4, Y5, Y6, Y7, Y8: XTAL-ABS07AIG-32.768KHZ-7-T; XTAL320X150X90

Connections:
!EN: J2.2, Q5.1, R19.2
!EN1: J9.2, Q9.1, R41.2
!EN2: J19.2, Q14.1, R63.2
!EN3: J28.2, Q19.1, R85.2
!EN4: J37.2, Q24.1, R107.2
!EN5: J46.2, Q29.1, R129.2
!EN6: J55.2, Q34.1, R151.2
!EN7: J64.2, Q39.1, R173.2
!RESET: J3.1, SW1.1, SW1.2, U1.32
!RESET1: J11.1, SW3.1, SW3.2, U7.32
!RESET2: J20.1, SW5.1, SW5.2, U19.32
!RESET3: J29.1, SW7.1, SW7.2, U28.32
!RESET4: J38.1, SW9.1, SW9.2, U37.32
!RESET5: J47.1, SW11.1, SW11.2, U46.32
!RESET6: J56.1, SW13.1, SW13.2, U55.32
!RESET7: J65.1, SW15.1, SW15.2, U64.32
+3V1: C18.1, C21.1, C25.1, C26.1, C28.1, C38.1, J11.2, J14.2, J17.1, R28.2, R29.2, R31.2, R38.2, R39.2, R44.2, U7.12, U7.22, U7.102, U10.8, U11.1, U11.10, U15.4, U18.9, U18.10
+3V2: C39.1, C40.1, C44.1, C45.1, C47.1, C57.1, J20.2, J23.2, J26.1, R50.2, R51.2, R53.2, R60.2, R61.2, R66.2, U19.12, U19.22, U19.102, U20.8, U21.1, U21.10, U24.4, U27.9, U27.10
+3V3: C3.1, C4.1, C5.1, C8.1, C10.1, C20.1, J3.2, J8.1, J10.2, R9.2, R11.2, R14.2, R17.2, R18.2, R23.2, U1.12, U1.22, U1.102, U3.1, U3.10, U4.4, U6.8, U12.9, U12.10
+3V4: C58.1, C59.1, C63.1, C64.1, C66.1, C76.1, J29.2, J32.2, J35.1, R72.2, R73.2, R75.2, R82.2, R83.2, R88.2, U28.12, U28.22, U28.102, U29.8, U30.1, U30.10, U33.4, U36.9, U36.10
+3V5: C77.1, C78.1, C82.1, C83.1, C85.1, C95.1, J38.2, J41.2, J44.1, R94.2, R95.2, R97.2, R104.2, R105.2, R110.2, U37.12, U37.22, U37.102, U38.8, U39.1, U39.10, U42.4, U45.9, U45.10
+3V6: C96.1, C97.1, C101.1, C102.1, C104.1, C114.1, J47.2, J50.2, J53.1, R116.2, R117.2, R119.2, R126.2, R127.2, R132.2, U46.12, U46.22, U46.102, U47.8, U48.1, U48.10, U51.4, U54.9, U54.10
+3V7: C115.1, C116.1, C120.1, C121.1, C123.1, C133.1, J56.2, J59.2, J62.1, R138.2, R139.2, R141.2, R148.2, R149.2, R154.2, U55.12, U55.22, U55.102, U56.8, U57.1, U57.10, U60.4, U63.9, U63.10
+3V8: C134.1, C135.1, C139.1, C140.1, C142.1, C152.1, J65.2, J68.2, J71.1, R160.2, R161.2, R163.2, R170.2, R171.2, R176.2, U64.12, U64.22, U64.102, U65.8, U66.1, U66.10, U69.4, U72.9, U72.10
ANT: C1.2, C2.1, U1.61
ANT1: C24.2, C37.1, U7.61
ANT2: C43.2, C56.1, U19.61
ANT3: C62.2, C75.1, U28.61
ANT4: C81.2, C94.1, U37.61
ANT5: C100.2, C113.1, U46.61
ANT6: C119.2, C132.1, U55.61
ANT7: C138.2, C151.1, U64.61
ANT_FILT: C1.1, J4.1, L1.2
ANT_FILT1: C24.1, J12.1, L5.2
ANT_FILT2: C43.1, J21.1, L8.2
ANT_FILT3: C62.1, J30.1, L11.2
ANT_FILT4: C81.1, J39.1, L14.2
ANT_FILT5: C100.1, J48.1, L17.2
ANT_FILT6: C119.1, J57.1, L20.2
ANT_FILT7: C138.1, J66.1, L23.2
CHRG: D4.C, U2.1
CHRG1: D2.C, U16.1
CHRG2: D10.C, U25.1
CHRG3: D14.C, U34.1
CHRG4: D18.C, U43.1
CHRG5: D22.C, U52.1
CHRG6: D26.C, U61.1
CHRG7: D30.C, U70.1
COEX0/LNA_EN: R1.2, U1.93, U4.6
COEX0/LNA_EN1: R40.2, U7.93, U15.6
COEX0/LNA_EN2: R62.2, U19.93, U24.6
COEX0/LNA_EN3: R84.2, U28.93, U33.6
COEX0/LNA_EN4: R106.2, U37.93, U42.6
COEX0/LNA_EN5: R128.2, U46.93, U51.6
COEX0/LNA_EN6: R150.2, U55.93, U60.6
COEX0/LNA_EN7: R172.2, U64.93, U69.6
CP212_VBUS: R15.1, R16.2, U5.8
CP212_VBUS1: R35.1, R36.2, U17.8
CP212_VBUS2: R57.1, R58.2, U26.8
CP212_VBUS3: R79.1, R80.2, U35.8
CP212_VBUS4: R101.1, R102.2, U44.8
CP212_VBUS5: R123.1, R124.2, U53.8
CP212_VBUS6: R145.1, R146.2, U62.8
CP212_VBUS7: R167.1, R168.2, U71.8
CP2102N-!RST: R4.1, U5.9
CP2102N-!RST1: R33.1, U17.9
CP2102N-!RST2: R55.1, U26.9
CP2102N-!RST3: R77.1, U35.9
CP2102N-!RST4: R99.1, U44.9
CP2102N-!RST5: R121.1, U53.9
CP2102N-!RST6: R143.1, U62.9
CP2102N-!RST7: R165.1, U71.9
CP2102N-VDD: C15.1, C16.1, R4.2, U5.5, U5.6
CP2102N-VDD1: C32.1, C33.1, R33.2, U17.5, U17.6
CP2102N-VDD2: C51.1, C52.1, R55.2, U26.5, U26.6
CP2102N-VDD3: C70.1, C71.1, R77.2, U35.5, U35.6
CP2102N-VDD4: C89.1, C90.1, R99.2, U44.5, U44.6
CP2102N-VDD5: C108.1, C109.1, R121.2, U53.5, U53.6
CP2102N-VDD6: C127.1, C128.1, R143.2, U62.5, U62.6
CP2102N-VDD7: C146.1, C147.1, R165.2, U71.5, U71.6
DIFF_N: J1.A7, J1.B7, U5.4
DIFF_N1: J15.A7, J15.B7, U17.4
DIFF_N2: J24.A7, J24.B7, U26.4
DIFF_N3: J33.A7, J33.B7, U35.4
DIFF_N4: J42.A7, J42.B7, U44.4
DIFF_N5: J51.A7, J51.B7, U53.4
DIFF_N6: J60.A7, J60.B7, U62.4
DIFF_N7: J69.A7, J69.B7, U71.4
DIFF_P: J1.A6, J1.B6, U5.3
DIFF_P1: J15.A6, J15.B6, U17.3
DIFF_P2: J24.A6, J24.B6, U26.3
DIFF_P3: J33.A6, J33.B6, U35.3
DIFF_P4: J42.A6, J42.B6, U44.3
DIFF_P5: J51.A6, J51.B6, U53.3
DIFF_P6: J60.A6, J60.B6, U62.3
DIFF_P7: J69.A6, J69.B6, U71.3
FLASH_CS: U1.4, U6.1
FLASH_CS1: U7.4, U10.1
FLASH_CS2: U19.4, U20.1
FLASH_CS3: U28.4, U29.1
FLASH_CS4: U37.4, U38.1
FLASH_CS5: U46.4, U47.1
FLASH_CS6: U55.4, U56.1
FLASH_CS7: U64.4, U65.1
FLASH_HOLD: U1.18, U6.7
FLASH_HOLD1: U7.18, U10.7
FLASH_HOLD2: U19.18, U20.7
FLASH_HOLD3: U28.18, U29.7
FLASH_HOLD4: U37.18, U38.7
FLASH_HOLD5: U46.18, U47.7
FLASH_HOLD6: U55.18, U56.7
FLASH_HOLD7: U64.18, U65.7
FLASH_SCK: U1.19, U6.6
FLASH_SCK1: U7.19, U10.6
FLASH_SCK2: U19.19, U20.6
FLASH_SCK3: U28.19, U29.6
FLASH_SCK4: U37.19, U38.6
FLASH_SCK5: U46.19, U47.6
FLASH_SCK6: U55.19, U56.6
FLASH_SCK7: U64.19, U65.6
FLASH_SI: U1.16, U6.5
FLASH_SI1: U7.16, U10.5
FLASH_SI2: U19.16, U20.5
FLASH_SI3: U28.16, U29.5
FLASH_SI4: U37.16, U38.5
FLASH_SI5: U46.16, U47.5
FLASH_SI6: U55.16, U56.5
FLASH_SI7: U64.16, U65.5
FLASH_SO: U1.86, U6.2
FLASH_SO1: U7.86, U10.2
FLASH_SO2: U19.86, U20.2
FLASH_SO3: U28.86, U29.2
FLASH_SO4: U37.86, U38.2
FLASH_SO5: U46.86, U47.2
FLASH_SO6: U55.86, U56.2
FLASH_SO7: U64.86, U65.2
FLASH_WP: U1.15, U6.3
FLASH_WP1: U7.15, U10.3
FLASH_WP2: U19.15, U20.3
FLASH_WP3: U28.15, U29.3
FLASH_WP4: U37.15, U38.3
FLASH_WP5: U46.15, U47.3
FLASH_WP6: U55.15, U56.3
FLASH_WP7: U64.15, U65.3
GND: C2.2, C3.2, C4.2, C5.2, C6.2, C7.2, C8.2, C9.2, C10.2, C11.2, C13.2, C14.2, C15.2, C16.2, C17.2, C19.2, C20.2, J1.GND, J1.GND2, J1.SHLD1, J1.SHLD2, J1.SHLD3, J1.SHLD4, J3.4, J4.2, J4.3, J5.1, J6.G1, J6.G2, J6.G3, J6.G4, J6.S4, J7.2, J7.3, J8.3, J8.5, J8.9, J10.1, L1.1, Q2.1, Q4.2, Q5.2, R1.1, R2.1, R7.1, R8.1, R12.1, R13.1, R16.1, R19.1, R20.1, R21.1, SW1.3, SW1.4, U1.1, U1.5, U1.6, U1.7, U1.8, U1.9, U1.11, U1.14, U1.17, U1.21, U1.27, U1.31, U1.36, U1.41, U1.44, U1.47, U1.50, U1.52, U1.56, U1.60, U1.62, U1.63, U1.65, U1.66, U1.68, U1.69, U1.72, U1.74, U1.75, U1.76, U1.77, U1.78, U1.79, U1.80, U1.81, U1.82, U1.85, U1.90, U1.94, U1.98, U1.103_1, U1.103_2, U1.103_3, U1.103_4, U1.103_5, U1.103_6, U1.103_7, U1.103_8, U1.103_9, U1.103_10, U1.103_11, U1.103_12, U1.103_13, U1.103_14, U1.103_15, U1.103_16, U1.103_17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
GND1: C18.2, C21.2, C22.2, C23.2, C25.2, C26.2, C27.2, C28.2, C29.2, C30.2, C31.2, C32.2, C33.2, C35.2, C36.2, C37.2, C38.2, J11.4, J12.2, J12.3, J13.2, J13.3, J14.1, J15.GND, J15.GND2, J15.SHLD1, J15.SHLD2, J15.SHLD3, J15.SHLD4, J16.1, J17.3, J17.5, J17.9, J18.G1, J18.G2, J18.G3, J18.G4, J18.S4, L5.1, Q7.1, Q8.2, Q9.2, R22.1, R24.1, R26.1, R30.1, R32.1, R36.1, R40.1, R41.1, R42.1, R43.1, SW3.3, SW3.4, U7.1, U7.5, U7.6, U7.7, U7.8, U7.9, U7.11, U7.14, U7.17, U7.21, U7.27, U7.31, U7.36, U7.41, U7.44, U7.47, U7.50, U7.52, U7.56, U7.60, U7.62, U7.63, U7.65, U7.66, U7.68, U7.69, U7.72, U7.74, U7.75, U7.76, U7.77, U7.78, U7.79, U7.80, U7.81, U7.82, U7.85, U7.90, U7.94, U7.98, U7.103_1, U7.103_2, U7.103_3, U7.103_4, U7.103_5, U7.103_6, U7.103_7, U7.103_8, U7.103_9, U7.103_10, U7.103_11, U7.103_12, U7.103_13, U7.103_14, U7.103_15, U7.103_16, U7.103_17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
GND2: C39.2, C40.2, C41.2, C42.2, C44.2, C45.2, C46.2, C47.2, C48.2, C49.2, C50.2, C51.2, C52.2, C54.2, C55.2, C56.2, C57.2, J20.4, J21.2, J21.3, J22.2, J22.3, J23.1, J24.GND, J24.GND2, J24.SHLD1, J24.SHLD2, J24.SHLD3, J24.SHLD4, J25.1, J26.3, J26.5, J26.9, J27.G1, J27.G2, J27.G3, J27.G4, J27.S4, L8.1, Q12.1, Q13.2, Q14.2, R45.1, R46.1, R48.1, R52.1, R54.1, R58.1, R62.1, R63.1, R64.1, R65.1, SW5.3, SW5.4, U19.1, U19.5, U19.6, U19.7, U19.8, U19.9, U19.11, U19.14, U19.17, U19.21, U19.27, U19.31, U19.36, U19.41, U19.44, U19.47, U19.50, U19.52, U19.56, U19.60, U19.62, U19.63, U19.65, U19.66, U19.68, U19.69, U19.72, U19.74, U19.75, U19.76, U19.77, U19.78, U19.79, U19.80, U19.81, U19.82, U19.85, U19.90, U19.94, U19.98, U19.103_1, U19.103_2, U19.103_3, U19.103_4, U19.103_5, U19.103_6, U19.103_7, U19.103_8, U19.103_9, U19.103_10, U19.103_11, U19.103_12, U19.103_13, U19.103_14, U19.103_15, U19.103_16, U19.103_17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
GND3: C58.2, C59.2, C60.2, C61.2, C63.2, C64.2, C65.2, C66.2, C67.2, C68.2, C69.2, C70.2, C71.2, C73.2, C74.2, C75.2, C76.2, J29.4, J30.2, J30.3, J31.2, J31.3, J32.1, J33.GND, J33.GND2, J33.SHLD1, J33.SHLD2, J33.SHLD3, J33.SHLD4, J34.1, J35.3, J35.5, J35.9, J36.G1, J36.G2, J36.G3, J36.G4, J36.S4, L11.1, Q17.1, Q18.2, Q19.2, R67.1, R68.1, R70.1, R74.1, R76.1, R80.1, R84.1, R85.1, R86.1, R87.1, SW7.3, SW7.4, U28.1, U28.5, U28.6, U28.7, U28.8, U28.9, U28.11, U28.14, U28.17, U28.21, U28.27, U28.31, U28.36, U28.41, U28.44, U28.47, U28.50, U28.52, U28.56, U28.60, U28.62, U28.63, U28.65, U28.66, U28.68, U28.69, U28.72, U28.74, U28.75, U28.76, U28.77, U28.78, U28.79, U28.80, U28.81, U28.82, U28.85, U28.90, U28.94, U28.98, U28.103_1, U28.103_2, U28.103_3, U28.103_4, U28.103_5, U28.103_6, U28.103_7, U28.103_8, U28.103_9, U28.103_10, U28.103_11, U28.103_12, U28.103_13, U28.103_14, U28.103_15, U28.103_16, U28.103_17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
GND4: C77.2, C78.2, C79.2, C80.2, C82.2, C83.2, C84.2, C85.2, C86.2, C87.2, C88.2, C89.2, C90.2, C92.2, C93.2, C94.2, C95.2, J38.4, J39.2, J39.3, J40.2, J40.3, J41.1, J42.GND, J42.GND2, J42.SHLD1, J42.SHLD2, J42.SHLD3, J42.SHLD4, J43.1, J44.3, J44.5, J44.9, J45.G1, J45.G2, J45.G3, J45.G4, J45.S4, L14.1, Q22.1, Q23.2, Q24.2, R89.1, R90.1, R92.1, R96.1, R98.1, R102.1, R106.1, R107.1, R108.1, R109.1, SW9.3, SW9.4, U37.1, U37.5, U37.6, U37.7, U37.8, U37.9, U37.11, U37.14, U37.17, U37.21, U37.27, U37.31, U37.36, U37.41, U37.44, U37.47, U37.50, U37.52, U37.56, U37.60, U37.62, U37.63, U37.65, U37.66, U37.68, U37.69, U37.72, U37.74, U37.75, U37.76, U37.77, U37.78, U37.79, U37.80, U37.81, U37.82, U37.85, U37.90, U37.94, U37.98, U37.103_1, U37.103_2, U37.103_3, U37.103_4, U37.103_5, U37.103_6, U37.103_7, U37.103_8, U37.103_9, U37.103_10, U37.103_11, U37.103_12, U37.103_13, U37.103_14, U37.103_15, U37.103_16, U37.103_17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
GND5: C96.2, C97.2, C98.2, C99.2, C101.2, C102.2, C103.2, C104.2, C105.2, C106.2, C107.2, C108.2, C109.2, C111.2, C112.2, C113.2, C114.2, J47.4, J48.2, J48.3, J49.2, J49.3, J50.1, J51.GND, J51.GND2, J51.SHLD1, J51.SHLD2, J51.SHLD3, J51.SHLD4, J52.1, J53.3, J53.5, J53.9, J54.G1, J54.G2, J54.G3, J54.G4, J54.S4, L17.1, Q27.1, Q28.2, Q29.2, R111.1, R112.1, R114.1, R118.1, R120.1, R124.1, R128.1, R129.1, R130.1, R131.1, SW11.3, SW11.4, U46.1, U46.5, U46.6, U46.7, U46.8, U46.9, U46.11, U46.14, U46.17, U46.21, U46.27, U46.31, U46.36, U46.41, U46.44, U46.47, U46.50, U46.52, U46.56, U46.60, U46.62, U46.63, U46.65, U46.66, U46.68, U46.69, U46.72, U46.74, U46.75, U46.76, U46.77, U46.78, U46.79, U46.80, U46.81, U46.82, U46.85, U46.90, U46.94, U46.98, U46.103_1, U46.103_2, U46.103_3, U46.103_4, U46.103_5, U46.103_6, U46.103_7, U46.103_8, U46.103_9, U46.103_10, U46.103_11, U46.103_12, U46.103_13, U46.103_14, U46.103_15, U46.103_16, U46.103_17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
GND6: C115.2, C116.2, C117.2, C118.2, C120.2, C121.2, C122.2, C123.2, C124.2, C125.2, C126.2, C127.2, C128.2, C130.2, C131.2, C132.2, C133.2, J56.4, J57.2, J57.3, J58.2, J58.3, J59.1, J60.GND, J60.GND2, J60.SHLD1, J60.SHLD2, J60.SHLD3, J60.SHLD4, J61.1, J62.3, J62.5, J62.9, J63.G1, J63.G2, J63.G3, J63.G4, J63.S4, L20.1, Q32.1, Q33.2, Q34.2, R133.1, R134.1, R136.1, R140.1, R142.1, R146.1, R150.1, R151.1, R152.1, R153.1, SW13.3, SW13.4, U55.1, U55.5, U55.6, U55.7, U55.8, U55.9, U55.11, U55.14, U55.17, U55.21, U55.27, U55.31, U55.36, U55.41, U55.44, U55.47, U55.50, U55.52, U55.56, U55.60, U55.62, U55.63, U55.65, U55.66, U55.68, U55.69, U55.72, U55.74, U55.75, U55.76, U55.77, U55.78, U55.79, U55.80, U55.81, U55.82, U55.85, U55.90, U55.94, U55.98, U55.103_1, U55.103_2, U55.103_3, U55.103_4, U55.103_5, U55.103_6, U55.103_7, U55.103_8, U55.103_9, U55.103_10, U55.103_11, U55.103_12, U55.103_13, U55.103_14, U55.103_15, U55.103_16, U55.103_17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

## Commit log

2020-09-18 First commit of nRF9160 Thing Plus
    [nRF9160 Thing Plus.brd, nRF9160 Thing Plus.sch]
2020-10-07 Changed C9 to match other 4.7u caps. Update D5/D6 to BAT60A Updated J5 to match Sparkfun's JST connector
    [nRF9160 Thing Plus.brd, nRF9160 Thing Plus.sch]
2020-10-19 Modifying mode pin to be connected directly to the MD button. (useful for external wakeup)
    [nRF9160 Thing Plus.brd, nRF9160 Thing Plus.sch]
2020-10-30 Adding LIS2DH12TR and supporting components. Adding jumpers for D2 (Accel int) and also PS_EN
    [nRF9160 Thing Plus.brd, nRF9160 Thing Plus.sch]
2020-10-30 Adding XYZ label
    [nRF9160 Thing Plus.brd]
2020-10-30 Thing Plus label
    [nRF9160 Thing Plus.brd]
2020-10-30 Updated name label and eSIM cream
    [nRF9160 Thing Plus.brd, nRF9160 Thing Plus.sch]
2020-11-10 Moved components to local libraries
    Parts not in SFE Eagle libraries were moved to local temporary libraries with the SFE SKUs added for the BOM
    [nRF9160 Thing Plus.brd, nRF9160 Thing Plus.sch]
2020-12-01 Updating SDA/SCL labels
    [nRF9160 Thing Plus.brd]
2020-12-02 Adding Cortex-m header. Removing tag connect. Removing external SIM bits. Changing SIM holder to cheaper variant.
    [nRF9160 Thing Plus.brd, nRF9160 Thing Plus.sch]
2020-12-02 Moving programming header up to get away from board edge.
    [nRF9160 Thing Plus.brd]
2021-01-07 Changing flash to W25Q32JVZPIQ. Changing D5/6 to BAT20J.
    [nRF9160 Thing Plus.brd, nRF9160 Thing Plus.sch]
2021-01-07 Adding test points for SIM
    [nRF9160 Thing Plus.brd, nRF9160 Thing Plus.sch]
2021-01-12 SF Update
    - Added PROD_ID info to new parts in temp libraries
    - Moved new parts to temp libraries
    - Added second fiducial to the top side of the board
    - Rotated buzzard labels for GPIO 0/SDA and 1/SCL to match the other labels
    - Shifted U9, R2, R7 to prevent overlap with reset label
    - Removed date text on layer 22 (bPlace) and replaced with version text on bottom copper layer
    [nRF9160 Thing Plus.brd, nRF9160 Thing Plus.sch]
2021-01-12 Cleaned up silkscreen labels around U9, R2, R7 Fixed some of the text related to fab export drawings.
    [nRF9160 Thing Plus.brd]
2021-01-13 Added Production Panel
    -Added production panel
    -Moved brd,sch, and library files to Hardware folder
    [nRF9160 Thing Plus-Panel.GBL, nRF9160 Thing Plus-Panel.GBO, nRF9160 Thing Plus-Panel.GBP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]
2021-01-13 Panel Fix
    Issues spotted:
    - USB-C connector was a two layer part instead of four. This caused an issue where the inner 3.3V copper layer was shorting to the ground layers on other layers through the USB support tabs.
    - Running the panelizer tool cause Eagle to crash.
    Changes Made:
    - Replaced USB-C connector with 4-layer footprint varient
    - Not sure what was causing Eagle to crash, but rotating the board 90 degrees fixed it
    - Silk on the bottom layer wasn't orientated correctly after rotating the board. Checking the "spin" box on the silk flipped the silk like it should be for "Designed by", "X", "Y", and "Z" labels
    Updated panel and gerbers with changes outlined above.
    [nRF9160 Thing Plus-Panel.GBL, nRF9160 Thing Plus-Panel.GBO, nRF9160 Thing Plus-Panel.GBP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]
2021-01-13 Moved Panel Files
    Moved panel files out of hardware folder
    [nRF9160 Thing Plus-Panel.GBL, nRF9160 Thing Plus-Panel.GBO, nRF9160 Thing Plus-Panel.GBP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]
2021-01-14 Updated nRF9160 paste footprint
    reduced the paste aperatures on some ground pads to minimize solder shorts
    [nRF9160 Thing Plus-Panel.brd, nRF9160 Thing Plus.brd, nRF9160 Thing Plus.sch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]
2021-03-31 Updated BOM
    replaced SW1 and SW2 to new taller momentary switch
    [nRF9160 Thing Plus.brd, nRF9160 Thing Plus.sch]

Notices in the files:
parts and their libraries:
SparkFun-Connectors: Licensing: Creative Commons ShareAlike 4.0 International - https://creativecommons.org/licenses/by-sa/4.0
